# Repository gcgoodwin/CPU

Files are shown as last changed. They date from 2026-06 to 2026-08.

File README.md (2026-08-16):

# Building an 8-Bit CPU from Transistors

I have used computers for most of my life, but for a long time the processor itself was basically a black box to me. I knew that code eventually became electrical signals, but I did not understand how a group of transistors could add numbers, remember data, or follow instructions. I started this project because I wanted to work through that entire path myself instead of only reading about it.

The long-term goal is still a complete 8-bit CPU. I originally tried to plan everything at once—the ALU, registers, program counter, control unit, clock, and memory interface—but I quickly realized that physically building all of that from discrete transistors would be a huge jump. I decided to make the first hardware milestone an **8-bit adder/subtractor**, since it is both manageable and something I can later reuse inside the ALU.

## Where I am right now

I started in LTspice, where I could build a gate, simulate it, and check its output before connecting it to anything else. From there, I combined gates into half adders and full adders and tested an 8-bit ripple-carry design. Simulation gave me a working plan, but transferring that plan onto a breadboard has been a completely different challenge.

I am currently building and testing the first 1-bit stage with 2N3904 NPN transistors. The three inputs are A, B, and a SUB/Cin input, and the two outputs are SUM and carry-out. I am powering the breadboard from an Arduino's 5 V pin while I test it.

The biggest difference from LTspice is that the real circuit does not tell me where I made a mistake. I have had to learn how the breadboard rows connect, check transistor orientation, test the input switches, and trace signals with a multimeter one node at a time. Even the output LEDs caused confusion.

## Project images

### LTspice design

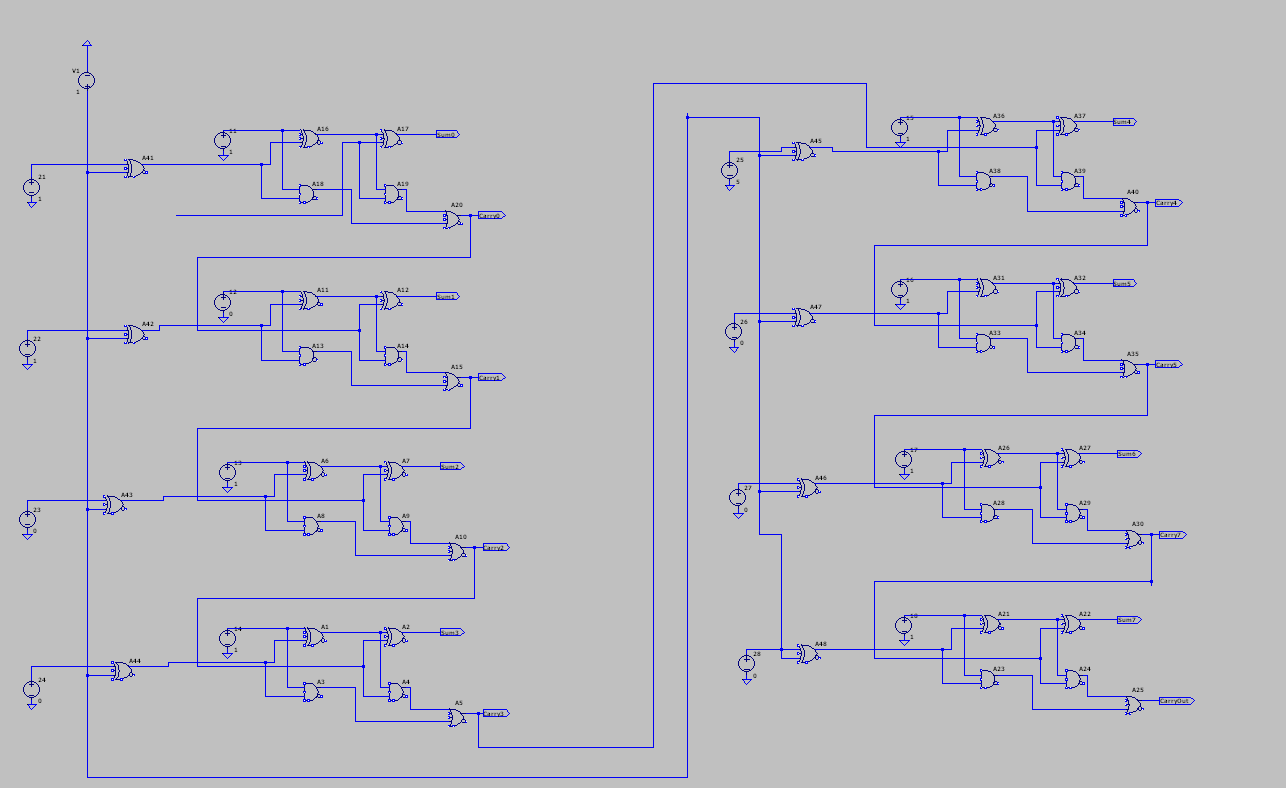
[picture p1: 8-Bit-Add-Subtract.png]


### Breadboard CAD

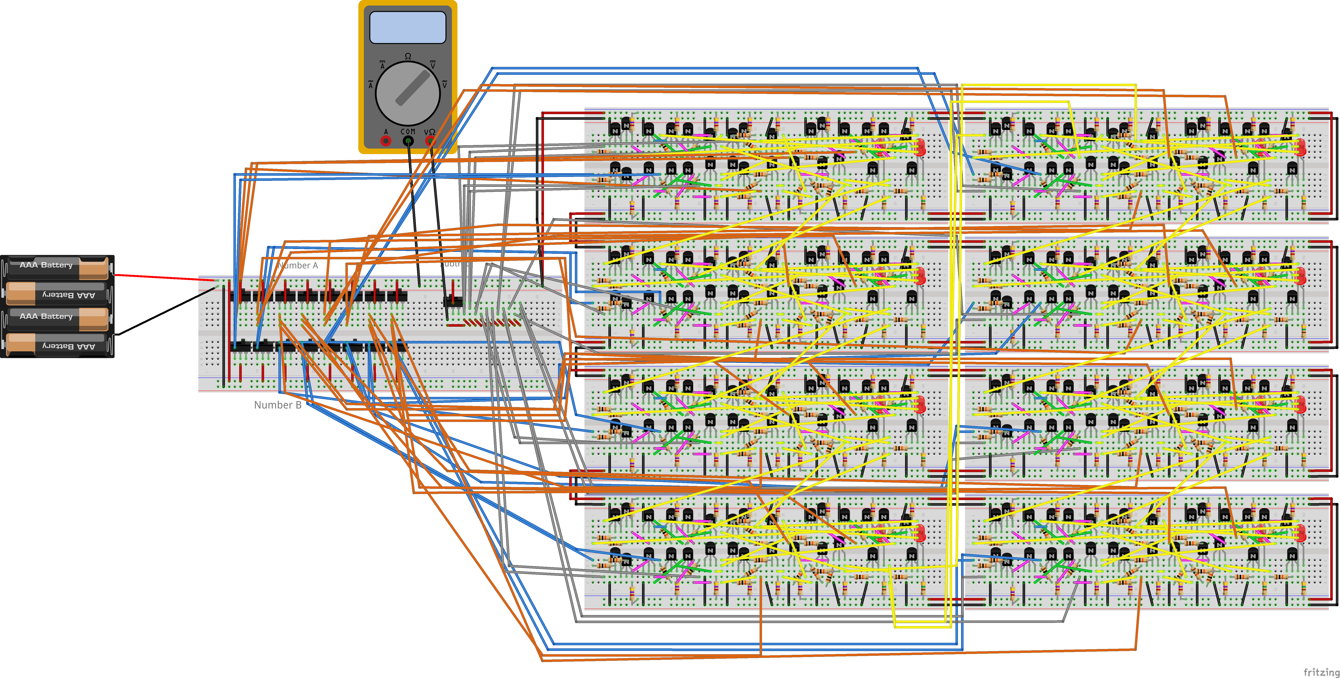
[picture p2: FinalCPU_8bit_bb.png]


### Physical build

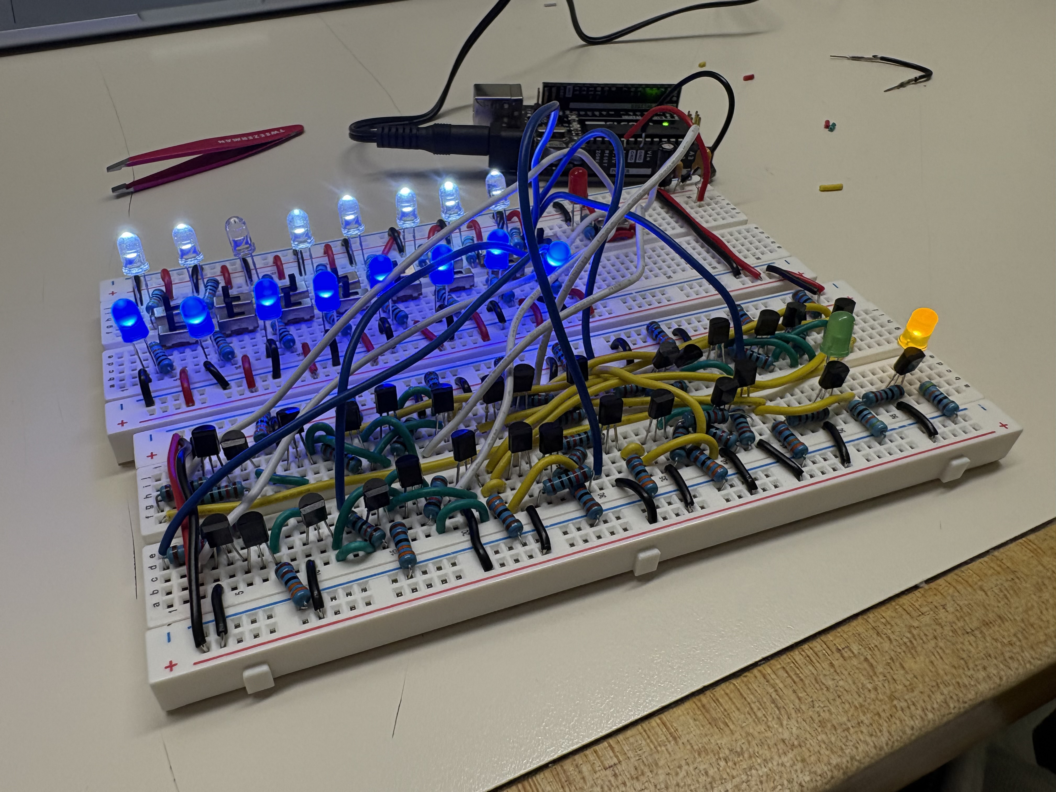
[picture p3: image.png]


## The active-low LED problem

During one test, I set `A = 1`, `B = 1`, and `Cin = 0`. I expected `SUM = 0` and `Cout = 1`, but the yellow SUM LED turned on while the green carry LED turned off. At first, I thought the full adder was producing the exact opposite of the correct answer.

After measuring the output transistor, I found that the carry collector was at 5 V while its base and emitter were at 0 V. The carry signal was actually correct. The confusing part was how I had connected the LEDs: each LED runs from 5 V through a 450 Ω resistor to an NPN collector. When the collector is LOW, the transistor sinks current and the LED turns on. When the collector is HIGH, both sides of the LED are near 5 V, so it turns off.

That means my current indicators are **active-low**:

- LED on = output `0`
- LED off = output `1`

Once I interpreted the LEDs correctly, the results followed the full-adder truth table. I added a 10 kΩ pull-up resistor to the carry collector so that its HIGH output reached 5 V instead of floating around 2.7 V. I still need to decide whether to keep the indicators active-low or spend an extra transistor and resistor on each output to make LED-on mean 1. For now, I am leaning toward keeping them active-low because the collector voltage itself is correct.

This was a useful debugging lesson because the circuit was not broken in the way I first assumed. I had to stop judging the output only by whether an LED was lit and measure the actual voltage instead.

## How addition and subtraction share one circuit

The finished 8-bit circuit will use eight full-adder stages connected in a ripple-carry arrangement. Each stage receives two data bits and the carry from the previous stage, then produces one result bit and a new carry.

For subtraction, the SUB input changes how operand B enters the adder. When `SUB = 1`, each B bit is inverted and the first carry-in is also set to 1. The adder therefore calculates:

`A + B̅ + 1 = A - B`

I originally expected subtraction to require a separate circuit, so learning that the same chain of full adders can perform both operations was one of the ideas that made me want to build this physically.

## Next steps

My immediate goal is to make the 1-bit stage reliable enough that I can duplicate it without copying an unnoticed wiring problem. After that, I will:

1. Build the remaining seven stages.
2. Connect each carry-out to the next carry-in.
3. Test addition with small values before moving to all eight bits.
4. Test subtraction and verify the two's-complement behavior.
5. Measure voltage levels between stages and check whether fan-out causes any problems.
6. Use the completed adder/subtractor as the arithmetic starting point for the ALU.

The later CPU stages are still plans, and I expect the design to change as I learn more from the physical build. Eventually, I want to add the remaining ALU operations, registers, a program counter, an instruction register, a control unit, a clock, and a memory interface.

## Planned ALU operations

| Opcode | Operation |
|:---:|---|
| `000` | Addition |
| `001` | Subtraction |
| `010` | Bitwise AND |
| `011` | Bitwise OR |
| `100` | Bitwise XOR |
| `101` | Bitwise NOT |
| `110` | Shift left |
| `111` | Shift right |

## Repository contents

- `ltspice/` contains my simulations for gates, adders, registers, and other CPU circuits.
- `cad/` contains the breadboard layout for the adder/subtractor.
- `docs/` contains schematics, architecture notes, screenshots, and hardware pictures.
- `journals/` records what I worked on, what failed, and what I changed.
- `parts-list/` tracks the components and cost of the physical build.

I am documenting the mistakes along with the finished circuits because being able to explain why something failed is part of understanding how it works. By the end of the project, I do not just want a processor that produces the right outputs. I want to know what every major section is doing and why it is connected the way it is.

## Author

**Goodwin Chen**  
Summer 2026

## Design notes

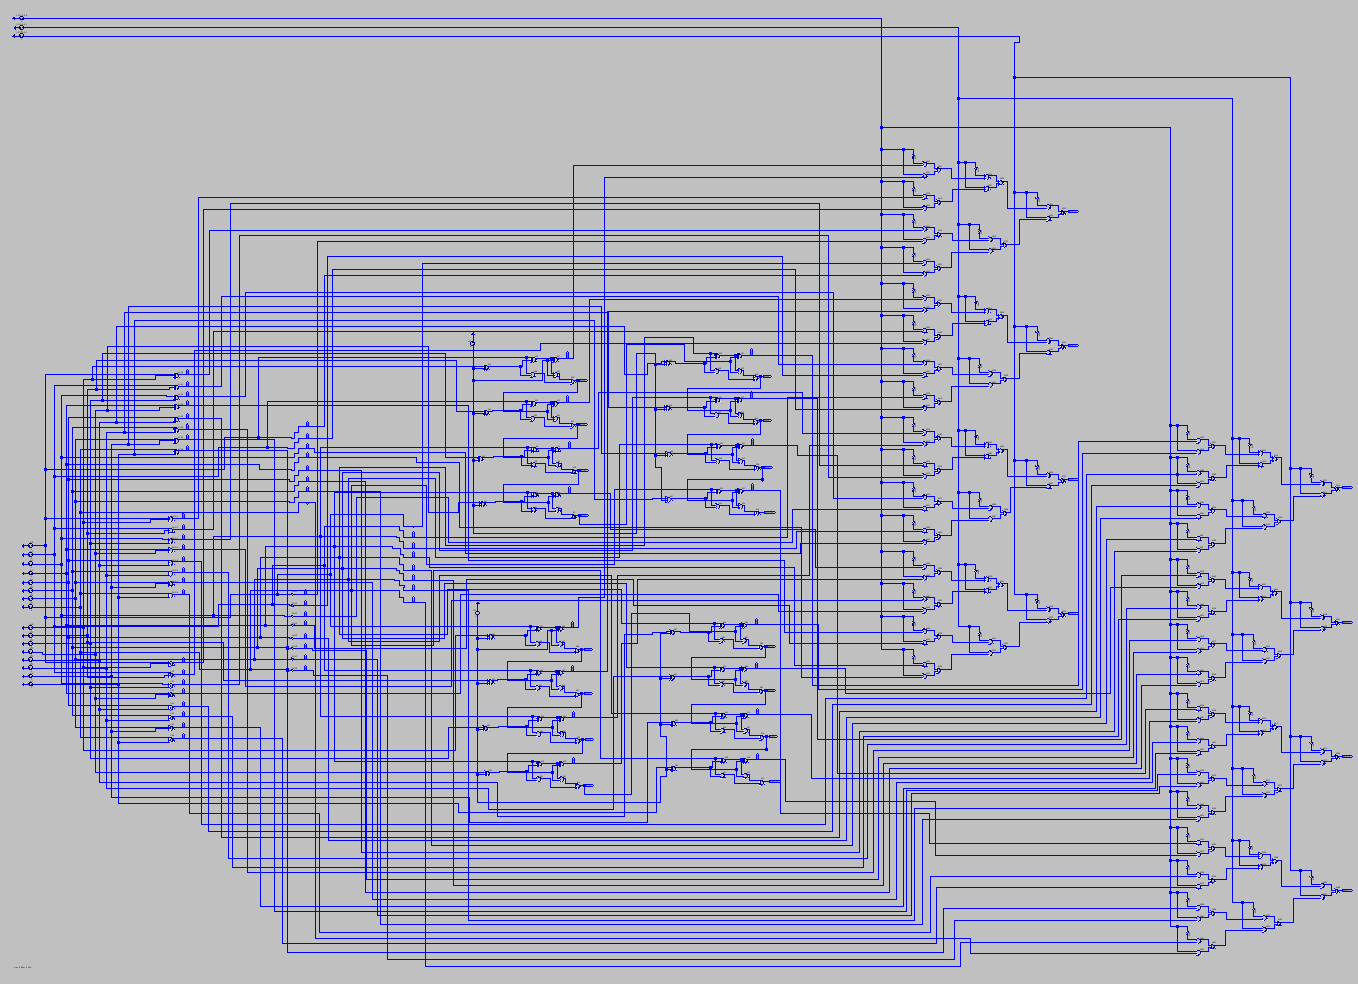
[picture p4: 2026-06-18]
Schematics/FULL-ALU-Schematic.png

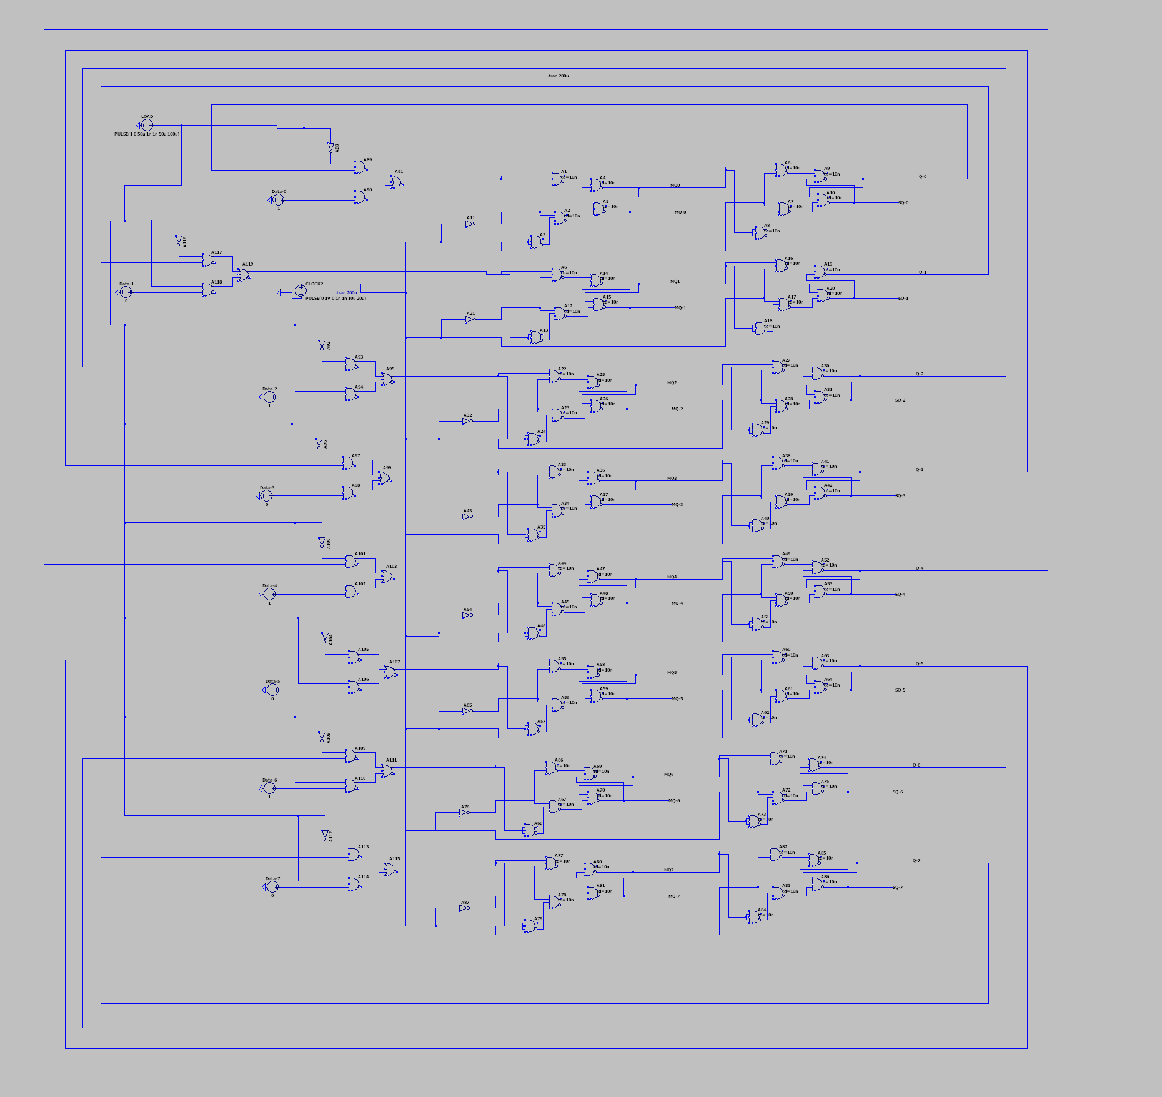
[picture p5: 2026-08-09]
Schematics/Screenshot 2026-08-08 at 11.20.06 PM.png

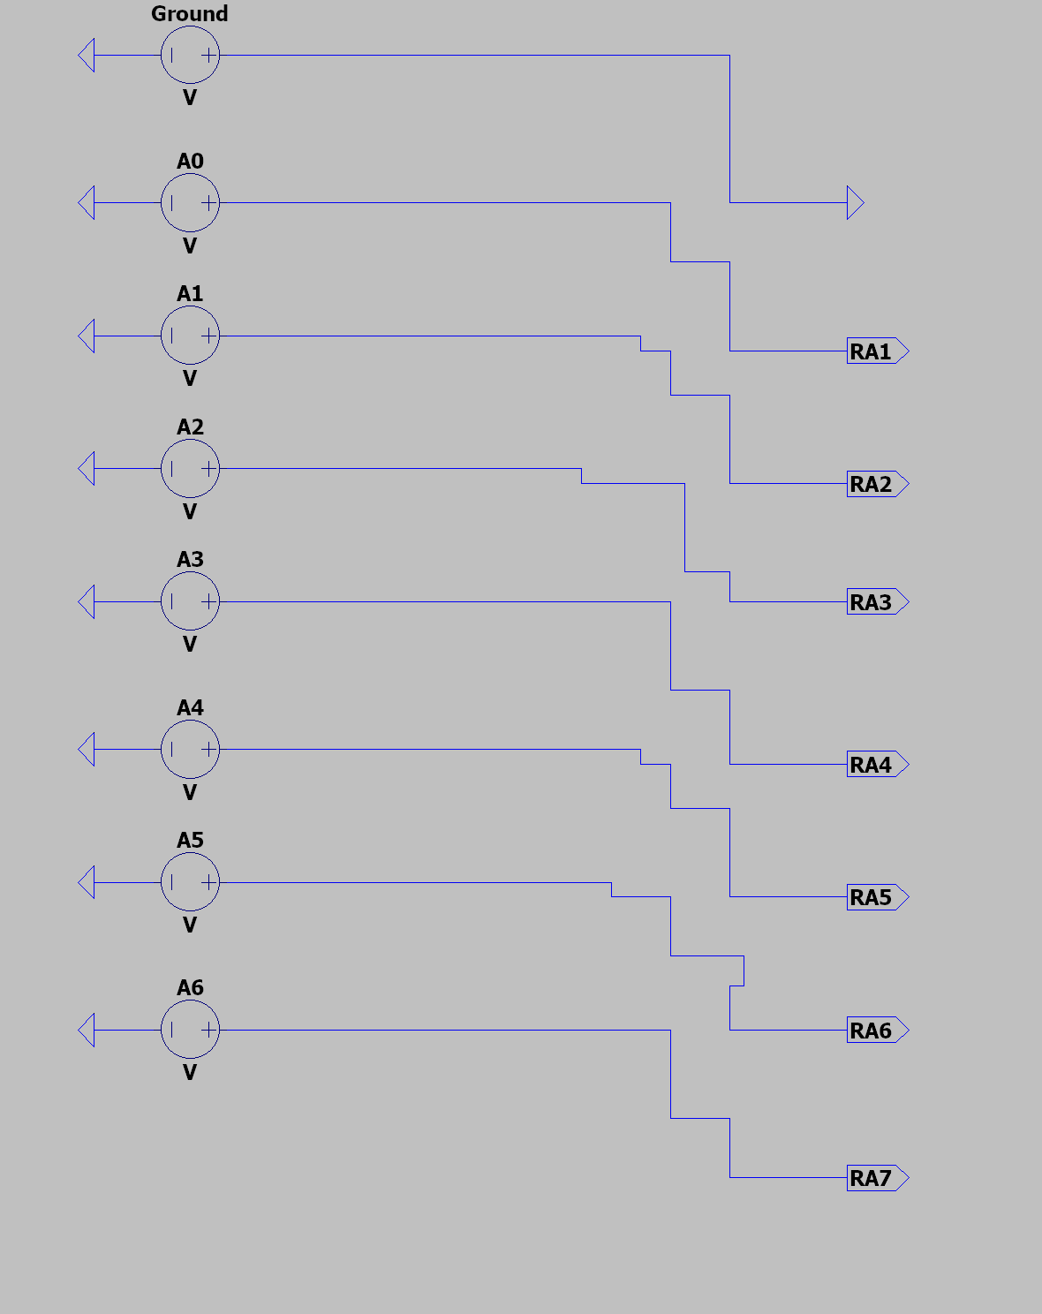
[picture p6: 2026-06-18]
Schematics/8-Bit-ShiftLeft.png

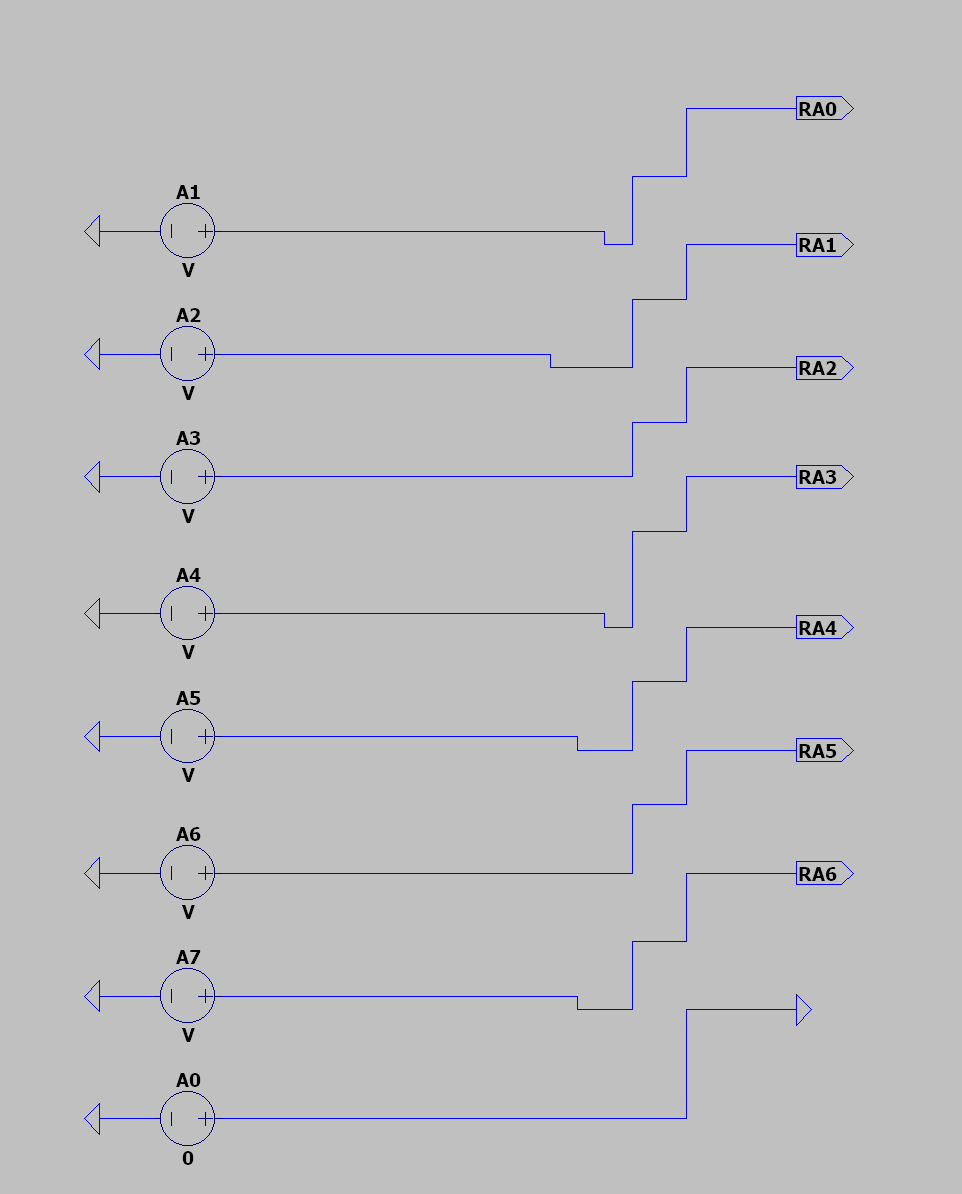
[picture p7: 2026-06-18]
Schematics/8-Bit-ShiftRight.png

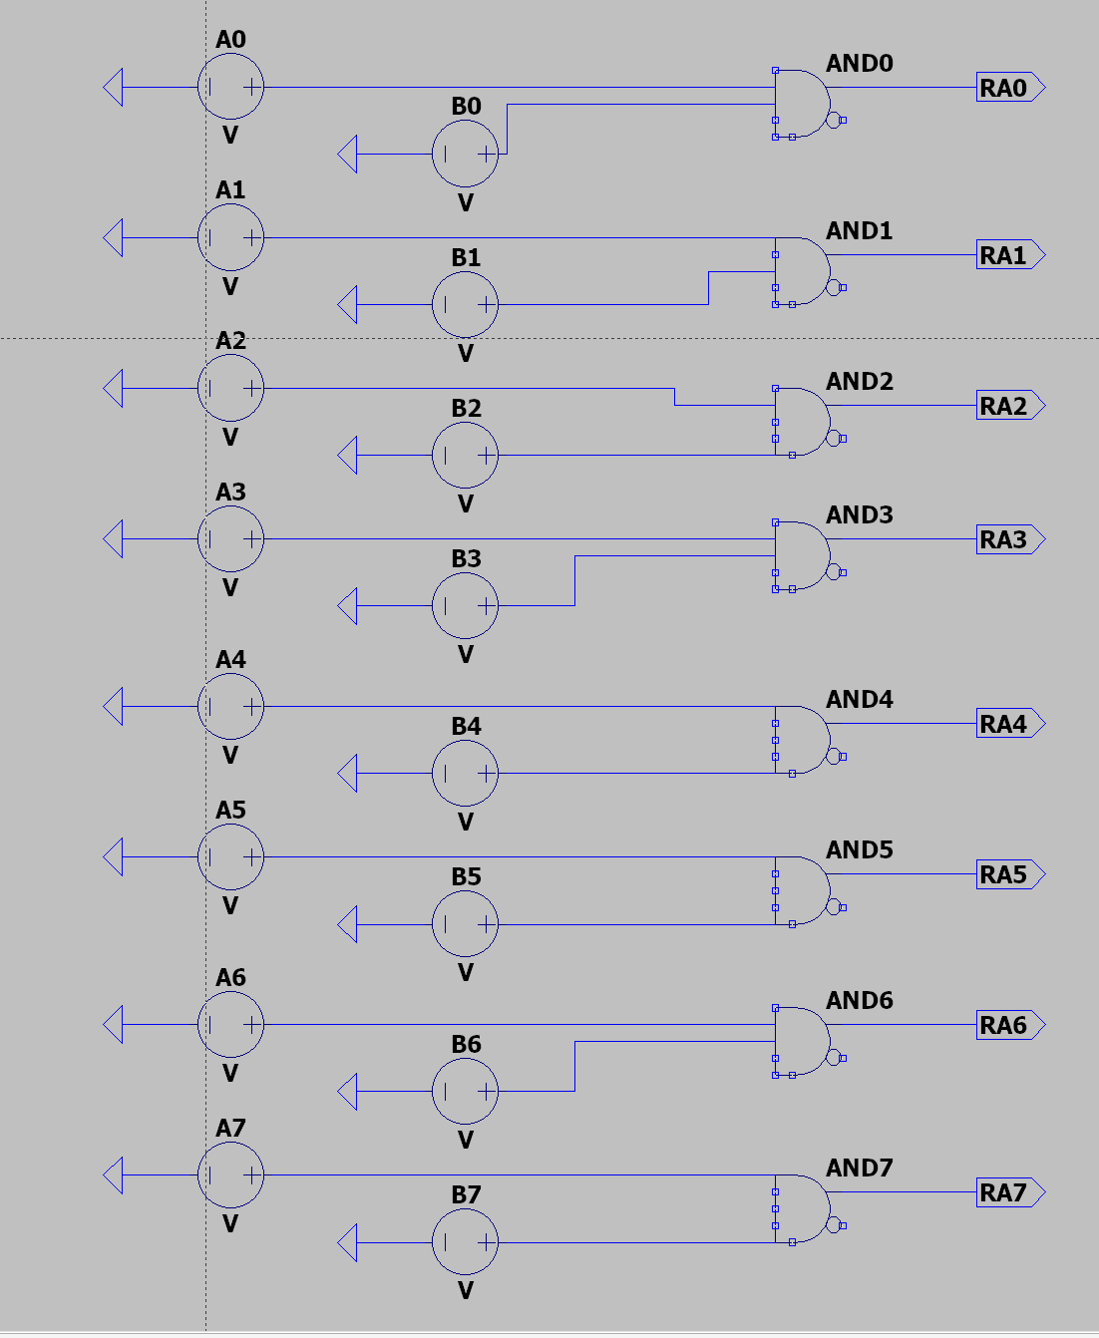
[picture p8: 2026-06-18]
Schematics/8-Bit-AND.png

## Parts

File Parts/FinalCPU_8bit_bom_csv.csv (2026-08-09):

Label | Part Type | mn | mpn | part number
LED1 | Red (633nm) LED
LED2 | Red (633nm) LED
LED3 | Red (633nm) LED
LED4 | Red (633nm) LED
LED5 | Red (633nm) LED
LED6 | Red (633nm) LED
LED7 | Red (633nm) LED
LED8 | Red (633nm) LED
LED9 | Red (633nm) LED
LED10 | Red (633nm) LED
LED11 | Red (633nm) LED
LED12 | Red (633nm) LED
LED13 | Red (633nm) LED
LED14 | Red (633nm) LED
LED15 | Red (633nm) LED
LED16 | Red (633nm) LED
Q2 | NPN-Transistor
Q3 | NPN-Transistor
Q4 | NPN-Transistor
Q5 | NPN-Transistor
Q6 | NPN-Transistor
Q7 | NPN-Transistor
Q8 | NPN-Transistor
Q9 | NPN-Transistor
Q10 | NPN-Transistor
Q11 | NPN-Transistor
Q12 | NPN-Transistor
Q13 | NPN-Transistor
Q14 | NPN-Transistor
Q15 | NPN-Transistor
Q16 | NPN-Transistor
Q17 | NPN-Transistor
Q18 | NPN-Transistor
Q19 | NPN-Transistor
Q20 | NPN-Transistor
Q21 | NPN-Transistor
Q22 | NPN-Transistor
Q23 | NPN-Transistor
Q24 | NPN-Transistor
Q25 | NPN-Transistor
Q26 | NPN-Transistor
Q27 | NPN-Transistor
Q28 | NPN-Transistor
Q29 | NPN-Transistor
Q30 | NPN-Transistor
Q31 | NPN-Transistor
Q32 | NPN-Transistor
Q33 | NPN-Transistor
Q34 | NPN-Transistor
Q35 | NPN-Transistor
Q36 | NPN-Transistor
Q37 | NPN-Transistor
Q38 | NPN-Transistor
Q39 | NPN-Transistor
Q40 | NPN-Transistor
Q41 | NPN-Transistor
Q42 | NPN-Transistor
Q43 | NPN-Transistor
Q44 | NPN-Transistor
Q45 | NPN-Transistor
Q46 | NPN-Transistor
Q47 | NPN-Transistor
Q48 | NPN-Transistor
Q49 | NPN-Transistor
Q50 | NPN-Transistor
Q51 | NPN-Transistor
Q52 | NPN-Transistor
Q53 | NPN-Transistor
Q54 | NPN-Transistor
Q55 | NPN-Transistor
Q56 | NPN-Transistor
Q57 | NPN-Transistor
Q58 | NPN-Transistor
Q59 | NPN-Transistor
Q60 | NPN-Transistor
Q61 | NPN-Transistor
Q62 | NPN-Transistor
Q63 | NPN-Transistor
Q64 | NPN-Transistor
Q65 | NPN-Transistor
Q66 | NPN-Transistor
Q67 | NPN-Transistor
Q68 | NPN-Transistor
Q69 | NPN-Transistor
Q70 | NPN-Transistor
Q71 | NPN-Transistor
Q72 | NPN-Transistor
Q73 | NPN-Transistor
Q74 | NPN-Transistor
Q75 | NPN-Transistor
Q76 | NPN-Transistor
Q77 | NPN-Transistor
Q78 | NPN-Transistor
Q79 | NPN-Transistor
Q80 | NPN-Transistor
Q81 | NPN-Transistor
Q82 | NPN-Transistor
Q83 | NPN-Transistor
Q84 | NPN-Transistor
Q85 | NPN-Transistor
Q86 | NPN-Transistor
Q87 | NPN-Transistor
Q88 | NPN-Transistor
Q89 | NPN-Transistor
Q90 | NPN-Transistor
Q91 | NPN-Transistor
Q92 | NPN-Transistor
Q93 | NPN-Transistor
Q94 | NPN-Transistor
Q95 | NPN-Transistor
Q96 | NPN-Transistor
Q97 | NPN-Transistor
Q98 | NPN-Transistor
Q99 | NPN-Transistor
Q100 | NPN-Transistor
Q101 | NPN-Transistor
Q102 | NPN-Transistor
Q103 | NPN-Transistor
Q104 | NPN-Transistor
Q105 | NPN-Transistor
Q106 | NPN-Transistor
Q107 | NPN-Transistor
Q108 | NPN-Transistor
Q109 | NPN-Transistor
Q110 | NPN-Transistor
Q111 | NPN-Transistor
Q112 | NPN-Transistor
Q113 | NPN-Transistor
Q114 | NPN-Transistor
Q115 | NPN-Transistor
Q116 | NPN-Transistor
Q117 | NPN-Transistor
Q118 | NPN-Transistor
Q119 | NPN-Transistor
Q120 | NPN-Transistor
Q121 | NPN-Transistor
Q122 | NPN-Transistor
Q123 | NPN-Transistor
Q124 | NPN-Transistor
Q125 | NPN-Transistor
Q126 | NPN-Transistor
Q127 | NPN-Transistor
Q128 | NPN-Transistor
Q129 | NPN-Transistor
Q130 | NPN-Transistor
Q131 | NPN-Transistor
Q132 | NPN-Transistor
Q133 | NPN-Transistor
Q134 | NPN-Transistor
Q135 | NPN-Transistor
Q136 | NPN-Transistor
Q137 | NPN-Transistor
Q138 | NPN-Transistor
Q139 | NPN-Transistor
Q140 | NPN-Transistor
Q141 | NPN-Transistor
Q142 | NPN-Transistor
Q143 | NPN-Transistor
Q144 | NPN-Transistor
Q145 | NPN-Transistor
Q146 | NPN-Transistor
Q147 | NPN-Transistor
Q148 | NPN-Transistor
Q149 | NPN-Transistor
Q150 | NPN-Transistor
Q151 | NPN-Transistor
Q152 | NPN-Transistor
Q153 | NPN-Transistor
Q154 | NPN-Transistor
Q155 | NPN-Transistor
Q156 | NPN-Transistor
Q157 | NPN-Transistor
Q158 | NPN-Transistor
Q159 | NPN-Transistor
Q160 | NPN-Transistor
Q161 | NPN-Transistor
Q162 | NPN-Transistor
Q163 | NPN-Transistor
Q164 | NPN-Transistor
Q165 | NPN-Transistor
Q166 | NPN-Transistor
Q167 | NPN-Transistor
Q168 | NPN-Transistor
Q169 | NPN-Transistor
Q170 | NPN-Transistor
Q171 | NPN-Transistor
Q172 | NPN-Transistor
Q173 | NPN-Transistor
Q174 | NPN-Transistor
Q175 | NPN-Transistor
Q176 | NPN-Transistor
Q177 | NPN-Transistor
Q178 | NPN-Transistor
Q179 | NPN-Transistor
Q180 | NPN-Transistor
Q181 | NPN-Transistor
Q182 | NPN-Transistor
Q183 | NPN-Transistor
Q184 | NPN-Transistor
Q185 | NPN-Transistor
Q186 | NPN-Transistor
Q187 | NPN-Transistor
Q188 | NPN-Transistor
Q189 | NPN-Transistor
Q190 | NPN-Transistor
Q191 | NPN-Transistor
Q192 | NPN-Transistor
Q193 | NPN-Transistor
Q194 | NPN-Transistor
Q195 | NPN-Transistor
Q196 | NPN-Transistor
Q197 | NPN-Transistor
Q198 | NPN-Transistor
Q199 | NPN-Transistor
Q200 | NPN-Transistor
Q201 | NPN-Transistor
Q202 | NPN-Transistor
Q203 | NPN-Transistor
Q204 | NPN-Transistor
Q205 | NPN-Transistor
Q206 | NPN-Transistor
Q207 | NPN-Transistor
Q208 | NPN-Transistor
Q209 | NPN-Transistor
Q210 | NPN-Transistor
Q211 | NPN-Transistor
Q212 | NPN-Transistor
Q213 | NPN-Transistor
Q214 | NPN-Transistor
Q215 | NPN-Transistor
Q216 | NPN-Transistor
Q217 | NPN-Transistor
Q218 | NPN-Transistor
Q219 | NPN-Transistor
Q220 | NPN-Transistor
Q221 | NPN-Transistor
Q222 | NPN-Transistor
Q223 | NPN-Transistor
Q224 | NPN-Transistor
Q225 | NPN-Transistor
Q226 | NPN-Transistor
Q227 | NPN-Transistor
Q228 | NPN-Transistor
Q229 | NPN-Transistor
Q230 | NPN-Transistor
Q231 | NPN-Transistor
Q232 | NPN-Transistor
Q233 | NPN-Transistor
R5 | 10kΩ Resistor
R6 | 10kΩ Resistor
R8 | 4.7kΩ Resistor
R9 | 4.7kΩ Resistor
R10 | 4.7kΩ Resistor
R13 | 10kΩ Resistor
R14 | 10kΩ Resistor
R15 | 10kΩ Resistor
R16 | 10kΩ Resistor
R17 | 4.7kΩ Resistor
R18 | 4.7kΩ Resistor
R19 | 4.7kΩ Resistor
R20 | 10kΩ Resistor
R21 | 10kΩ Resistor
R22 | 10kΩ Resistor
R23 | 4.7kΩ Resistor
R24 | 10kΩ Resistor
R25 | 4.7kΩ Resistor
R26 | 10kΩ Resistor
R27 | 10kΩ Resistor
R28 | 10kΩ Resistor
R29 | 10kΩ Resistor
R30 | 4.7kΩ Resistor
R31 | 4.7kΩ Resistor
R32 | 10kΩ Resistor
R33 | 10kΩ Resistor
R34 | 10kΩ Resistor
R35 | 10kΩ Resistor
R36 | 4.7kΩ Resistor
R37 | 4.7kΩ Resistor
R38 | 10kΩ Resistor
R39 | 10kΩ Resistor
R40 | 4.7kΩ Resistor
R41 | 4.7kΩ Resistor
R42 | 4.7kΩ Resistor
R43 | 10kΩ Resistor
R44 | 10kΩ Resistor
R45 | 450Ω Resistor
R46 | 450Ω Resistor
R47 | 10kΩ Resistor
R48 | 10kΩ Resistor
R49 | 10kΩ Resistor
R50 | 10kΩ Resistor
R51 | 10kΩ Resistor
R52 | 10kΩ Resistor
R53 | 10kΩ Resistor
R54 | 10kΩ Resistor
R55 | 10kΩ Resistor
R56 | 10kΩ Resistor
R57 | 10kΩ Resistor
R58 | 10kΩ Resistor
R59 | 450Ω Resistor
R60 | 450Ω Resistor
R61 | 4.7kΩ Resistor
R62 | 4.7kΩ Resistor
R63 | 4.7kΩ Resistor
R64 | 4.7kΩ Resistor
R65 | 4.7kΩ Resistor
R66 | 4.7kΩ Resistor
R67 | 4.7kΩ Resistor
R68 | 4.7kΩ Resistor
R69 | 4.7kΩ Resistor
R70 | 4.7kΩ Resistor
R71 | 4.7kΩ Resistor
R72 | 4.7kΩ Resistor
R73 | 4.7kΩ Resistor
R74 | 4.7kΩ Resistor
R75 | 4.7kΩ Resistor
R76 | 10kΩ Resistor
R77 | 10kΩ Resistor
R78 | 10kΩ Resistor
R79 | 10kΩ Resistor
R80 | 10kΩ Resistor
R81 | 10kΩ Resistor
R82 | 10kΩ Resistor
R83 | 10kΩ Resistor
R84 | 10kΩ Resistor
R85 | 10kΩ Resistor
R86 | 10kΩ Resistor
R87 | 10kΩ Resistor
R88 | 10kΩ Resistor
R89 | 10kΩ Resistor
R90 | 10kΩ Resistor
R91 | 10kΩ Resistor
R92 | 10kΩ Resistor
R93 | 10kΩ Resistor
R94 | 10kΩ Resistor
R95 | 10kΩ Resistor
R96 | 10kΩ Resistor
R97 | 10kΩ Resistor
R98 | 10kΩ Resistor
R99 | 10kΩ Resistor
R100 | 450Ω Resistor
R101 | 450Ω Resistor
R102 | 4.7kΩ Resistor
R103 | 4.7kΩ Resistor
R104 | 4.7kΩ Resistor
R105 | 4.7kΩ Resistor
R106 | 4.7kΩ Resistor
R107 | 4.7kΩ Resistor
R108 | 4.7kΩ Resistor
R109 | 4.7kΩ Resistor
R110 | 4.7kΩ Resistor
R111 | 4.7kΩ Resistor
R112 | 4.7kΩ Resistor
R113 | 4.7kΩ Resistor
R114 | 4.7kΩ Resistor
R115 | 4.7kΩ Resistor
R116 | 4.7kΩ Resistor
R117 | 10kΩ Resistor
R118 | 10kΩ Resistor
R119 | 10kΩ Resistor
R120 | 10kΩ Resistor
R121 | 10kΩ Resistor
R122 | 10kΩ Resistor
R123 | 10kΩ Resistor
R124 | 10kΩ Resistor
R125 | 10kΩ Resistor
R126 | 10kΩ Resistor
R127 | 10kΩ Resistor
R128 | 10kΩ Resistor
R129 | 10kΩ Resistor
R130 | 10kΩ Resistor
R131 | 10kΩ Resistor
R132 | 10kΩ Resistor
R133 | 10kΩ Resistor
R134 | 10kΩ Resistor
R135 | 10kΩ Resistor
R136 | 10kΩ Resistor
R137 | 10kΩ Resistor
R138 | 10kΩ Resistor
R139 | 10kΩ Resistor
R140 | 10kΩ Resistor
R141 | 450Ω Resistor
R142 | 450Ω Resistor
R143 | 4.7kΩ Resistor
R144 | 4.7kΩ Resistor
R145 | 4.7kΩ Resistor
R146 | 4.7kΩ Resistor
R147 | 4.7kΩ Resistor
R148 | 4.7kΩ Resistor
R149 | 4.7kΩ Resistor
R150 | 4.7kΩ Resistor
R151 | 4.7kΩ Resistor
R152 | 4.7kΩ Resistor
R153 | 4.7kΩ Resistor
R154 | 4.7kΩ Resistor
R155 | 4.7kΩ Resistor
R156 | 4.7kΩ Resistor
R157 | 4.7kΩ Resistor
R158 | 10kΩ Resistor
R159 | 10kΩ Resistor
R160 | 10kΩ Resistor
R161 | 10kΩ Resistor
R162 | 10kΩ Resistor
R163 | 10kΩ Resistor
R164 | 10kΩ Resistor
R165 | 10kΩ Resistor
R166 | 10kΩ Resistor
R167 | 10kΩ Resistor
R168 | 10kΩ Resistor
R169 | 10kΩ Resistor
R170 | 10kΩ Resistor
R171 | 10kΩ Resistor
R172 | 10kΩ Resistor
R173 | 10kΩ Resistor
R174 | 10kΩ Resistor
R175 | 10kΩ Resistor
R176 | 10kΩ Resistor
R177 | 10kΩ Resistor
R178 | 10kΩ Resistor
R179 | 10kΩ Resistor
R180 | 10kΩ Resistor
R181 | 10kΩ Resistor
R182 | 450Ω Resistor
R183 | 450Ω Resistor
R184 | 4.7kΩ Resistor
R185 | 4.7kΩ Resistor
R186 | 4.7kΩ Resistor
R187 | 4.7kΩ Resistor
R188 | 4.7kΩ Resistor
R189 | 4.7kΩ Resistor
R190 | 4.7kΩ Resistor
R191 | 4.7kΩ Resistor
R192 | 4.7kΩ Resistor
R193 | 4.7kΩ Resistor
R194 | 4.7kΩ Resistor
R195 | 4.7kΩ Resistor
R196 | 4.7kΩ Resistor
R197 | 4.7kΩ Resistor
R198 | 4.7kΩ Resistor
R199 | 10kΩ Resistor
R200 | 10kΩ Resistor
R201 | 10kΩ Resistor
R202 | 10kΩ Resistor
R203 | 10kΩ Resistor
R204 | 10kΩ Resistor
R205 | 10kΩ Resistor
R206 | 10kΩ Resistor
R207 | 10kΩ Resistor
R208 | 10kΩ Resistor
R209 | 10kΩ Resistor
R210 | 10kΩ Resistor
R211 | 10kΩ Resistor
R212 | 10kΩ Resistor
R213 | 10kΩ Resistor
R214 | 10kΩ Resistor
R215 | 10kΩ Resistor
R216 | 10kΩ Resistor
R217 | 10kΩ Resistor
R218 | 10kΩ Resistor
R219 | 10kΩ Resistor
R220 | 10kΩ Resistor
R221 | 10kΩ Resistor
R222 | 10kΩ Resistor
R223 | 450Ω Resistor
R224 | 450Ω Resistor
R225 | 4.7kΩ Resistor
R226 | 4.7kΩ Resistor
R227 | 4.7kΩ Resistor
R228 | 4.7kΩ Resistor
R229 | 4.7kΩ Resistor
R230 | 4.7kΩ Resistor
R231 | 4.7kΩ Resistor
R232 | 4.7kΩ Resistor
R233 | 4.7kΩ Resistor
R234 | 4.7kΩ Resistor
R235 | 4.7kΩ Resistor
R236 | 4.7kΩ Resistor
R237 | 4.7kΩ Resistor
R238 | 4.7kΩ Resistor
R239 | 4.7kΩ Resistor
R240 | 10kΩ Resistor
R241 | 10kΩ Resistor
R242 | 10kΩ Resistor
R243 | 10kΩ Resistor
R244 | 10kΩ Resistor
R245 | 10kΩ Resistor
R246 | 10kΩ Resistor
R247 | 10kΩ Resistor
R248 | 10kΩ Resistor
R249 | 10kΩ Resistor
R250 | 10kΩ Resistor
R251 | 10kΩ Resistor
R252 | 10kΩ Resistor
R253 | 10kΩ Resistor
R254 | 10kΩ Resistor
R255 | 10kΩ Resistor
R256 | 10kΩ Resistor
R257 | 10kΩ Resistor
R258 | 10kΩ Resistor
R259 | 10kΩ Resistor
R260 | 10kΩ Resistor
R261 | 10kΩ Resistor
R262 | 10kΩ Resistor
R263 | 10kΩ Resistor
R264 | 450Ω Resistor
R265 | 450Ω Resistor
R266 | 4.7kΩ Resistor
R267 | 4.7kΩ Resistor
R268 | 4.7kΩ Resistor
R269 | 4.7kΩ Resistor
R270 | 4.7kΩ Resistor
R271 | 4.7kΩ Resistor
R272 | 4.7kΩ Resistor
R273 | 4.7kΩ Resistor
R274 | 4.7kΩ Resistor
R275 | 4.7kΩ Resistor
R276 | 4.7kΩ Resistor
R277 | 4.7kΩ Resistor
R278 | 4.7kΩ Resistor
R279 | 4.7kΩ Resistor
R280 | 4.7kΩ Resistor
R281 | 10kΩ Resistor
R282 | 10kΩ Resistor
R283 | 10kΩ Resistor
R284 | 10kΩ Resistor
R285 | 10kΩ Resistor
R286 | 10kΩ Resistor
R287 | 10kΩ Resistor
R288 | 10kΩ Resistor
R289 | 10kΩ Resistor
R290 | 10kΩ Resistor
R291 | 10kΩ Resistor
R292 | 10kΩ Resistor
R293 | 10kΩ Resistor
R294 | 10kΩ Resistor
R295 | 10kΩ Resistor
R296 | 10kΩ Resistor
R297 | 10kΩ Resistor
R298 | 10kΩ Resistor
R299 | 10kΩ Resistor
R300 | 10kΩ Resistor
R301 | 10kΩ Resistor
R302 | 10kΩ Resistor
R303 | 10kΩ Resistor
R304 | 10kΩ Resistor
R305 | 450Ω Resistor
R306 | 450Ω Resistor
R307 | 4.7kΩ Resistor
R308 | 4.7kΩ Resistor
R309 | 4.7kΩ Resistor
R310 | 4.7kΩ Resistor
R311 | 4.7kΩ Resistor
R312 | 4.7kΩ Resistor
R313 | 4.7kΩ Resistor
R314 | 4.7kΩ Resistor
R315 | 4.7kΩ Resistor
R316 | 4.7kΩ Resistor
R317 | 4.7kΩ Resistor
R318 | 4.7kΩ Resistor
R319 | 4.7kΩ Resistor
R320 | 4.7kΩ Resistor
R321 | 4.7kΩ Resistor
R322 | 10kΩ Resistor
R323 | 10kΩ Resistor
R324 | 10kΩ Resistor
R325 | 10kΩ Resistor
R326 | 10kΩ Resistor
R327 | 10kΩ Resistor
R328 | 10kΩ Resistor
R329 | 10kΩ Resistor
R330 | 10kΩ Resistor
R331 | 10kΩ Resistor
R332 | 10kΩ Resistor
R333 | 10kΩ Resistor
R334 | 10kΩ Resistor
R335 | 10kΩ Resistor
S1 | Toggle Switch
S2 | Toggle Switch
S3 | Toggle Switch
S4 | Toggle Switch
S5 | Toggle Switch
S6 | Toggle Switch
S7 | Toggle Switch
S8 | Toggle Switch
S9 | Toggle Switch
S10 | Toggle Switch
S11 | Toggle Switch
S12 | Toggle Switch
S13 | Toggle Switch
S14 | Toggle Switch
S15 | Toggle Switch
S16 | Toggle Switch
S17 | Toggle Switch
VCC2 | 4 x AAA Battery Mount
VM1 | Multimeter (DC Voltage)
Amount | Part Type | mn | mpn | part number
192 | 10kΩ Resistor
1 | 4 x AAA Battery Mount
120 | 4.7kΩ Resistor
16 | 450Ω Resistor
1 | Multimeter (DC Voltage)
232 | NPN-Transistor
16 | Red (633nm) LED
17 | Toggle Switch

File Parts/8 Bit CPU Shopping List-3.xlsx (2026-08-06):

Item | Quanitity | Price | Ordered | Total
830 Tie Point Breadboard (https://www.amazon.com/EL-CP-003-Breadboard-Solderless-Distribution-Connecting/dp/B01EV6LJ7G?s=industrial) | 4 | 8.99 | FALSE | 120.67
Solid-core hookup wire (https://www.amazon.com/dp/B07TX6BX47?th=1) | 1 | 15.99 | FALSE
NPN Transisters 200x (https://www.amazon.com/BOJACK-2N3904-General-Purpose-Transistors/dp/B07T4ZJ76B) | 2 | 6.99 | FALSE
Resisters (https://www.amazon.com/BOJACK-Values-Resistor-Resistors-Assortment/dp/B08FD1XVL6?th=1) | 1 | 9.99 | FALSE
LED 3mm OR 5mm (https://www.amazon.com/CHANZON-Assortment-Colors-Clear-Transparent/dp/B01AUI4VSI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) | 1 | 6.99 | FALSE
3-Pin Switches (https://www.amazon.com/EGSCST-Switches-Position-Miniature-Vertical/dp/B0FNK8B1YV?th=1) | 1 | 8.99 | FALSE
Power Supply (https://www.amazon.com/Blomiky-2200mAH-Rechargeable-Battery-Charger/dp/B07FXVHT32) | 1 | 13.79 | FALSE
SM 2 Adapter for Battery (https://www.amazon.com/yueton-Pairs-Pins-Female-Connector/dp/B013L9N7KQ?s=electronics) | 1 | 5.99 | FALSE
DuPont Pins (https://www.amazon.com/gp/product/B096DNYH52/ref=ox_sc_act_title_1?smid=A1JGS66EYKMXOF&th=1) | 1 | 8.99 | FALSE
 |  |  | FALSE
 |  |  | FALSE
 |  |  | FALSE
 |  |  | FALSE
 |  |  | FALSE
 |  |  | FALSE

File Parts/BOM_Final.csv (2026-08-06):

Item | Quantity | Unit Price (USD) | Line Total (USD) | Ordered | Purchase Link
830-Tie-Point Breadboard | 4 | 8.99 | 35.96 | FALSE | https://www.amazon.com/dp/B01EV6LJ7G
Solid-Core Hookup Wire | 1 | 15.99 | 15.99 | FALSE | https://www.amazon.com/dp/B07TX6BX47
DuPont 2.54 mm Crimp Pins & 1-Pin Housings | 1 | 8.99 | 8.99 | FALSE | https://www.amazon.com/dp/B096DNYH52
NPN Transistors (200-Pack) | 2 | 6.99 | 13.98 | FALSE | https://www.amazon.com/dp/B07T4ZJ76B
Resistor Assortment | 1 | 9.99 | 9.99 | FALSE | https://www.amazon.com/dp/B08FD1XVL6
LED Pack (3 mm or 5 mm) | 1 | 6.99 | 6.99 | FALSE | https://www.amazon.com/dp/B01AUI4VSI
3-Pin SPDT Switches | 1 | 8.99 | 8.99 | FALSE | https://www.amazon.com/dp/B0FNK8B1YV
4.8 V Power Supply | 1 | 13.99 | 13.79 | FALSE | https://www.amazon.com/dp/B07FXVHT32
SM-2 Battery Adapter | 1 | 5.99 | 5.99 | FALSE | https://www.amazon.com/dp/B013L9N7KQ
TOTAL |  |  | 120.67

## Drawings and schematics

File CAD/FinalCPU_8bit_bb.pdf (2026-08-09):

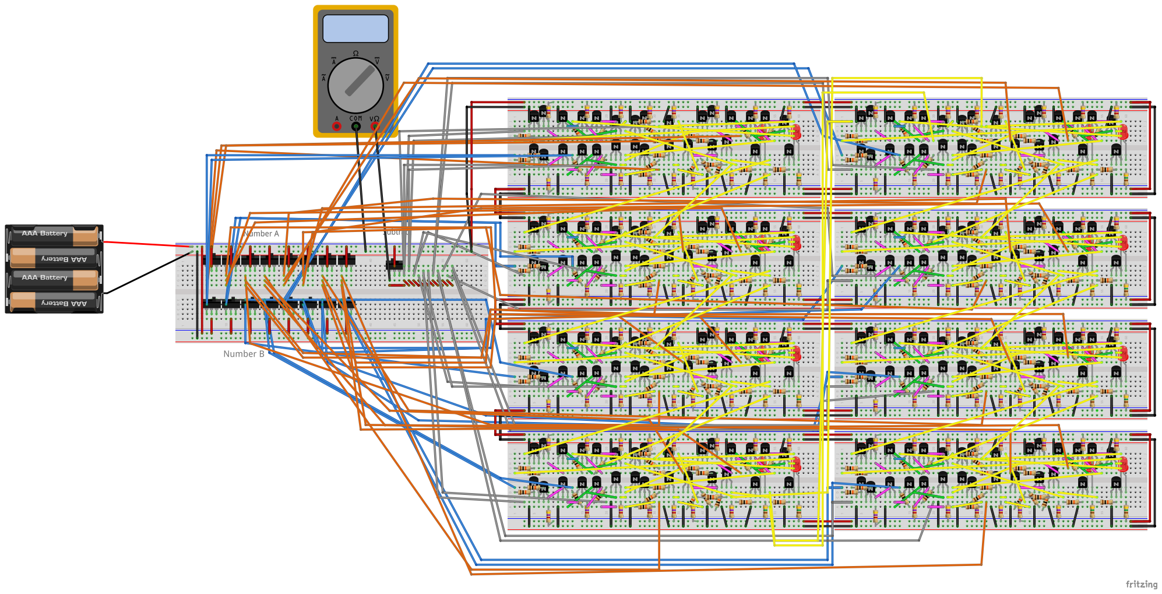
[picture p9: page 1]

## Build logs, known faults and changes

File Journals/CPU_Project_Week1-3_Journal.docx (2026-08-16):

CPU PROJECT

Three-Week Development Journal

Transistor-Level Logic, LTspice Simulation, PyRTL Conversion,
and Physical Adder Design

Student | Goodwin Chen
Project period | Three weeks, Summer 2026
Estimated work completed | Approximately 42 hours

A record of completed design, simulation, debugging, and documentation work

Project Description

I am building an 8-bit CPU from the transistor and gate level upward. The current physical hardware milestone is an 8-bit ripple-carry adder constructed from discrete NPN transistors. To reach that point, I designed and tested the required logic gates, full adders, multiplexers, shifting circuits, and an eight-function ALU in LTspice. I also developed a PyRTL-to-LTspice converter that translates digital designs into LTspice netlists and expanded it to support arithmetic, multiplexers, registers, clocked circuits, and feedback. For the physical implementation, I created a detailed one-bit full-adder layout in Fritzing, planned the complete eight-stage adder assembly, and prepared a professional bill of materials and budget. The adder serves as the arithmetic foundation for the larger CPU documented in the GitHub repository.

Journal scope: This journal records work already completed. Because I did not track every session with a timer, the hour totals are professional estimates based on the amount of design, simulation, debugging, and documentation completed.

Progress at a Glance

Week | Primary Focus | Major Deliverables | Hours
1 | LTspice logic and ALU design | Transistor-level gates, full adder, ripple-carry structure, shifts, multiplexers, and complete 8-bit ALU | 16
2 | PyRTL-to-LTspice converter | Operation mapping, reusable cells, register support, DFF validation, 8-bit register, and 4-bit counter | 15
3 | Physical layout and build planning | Fritzing full-adder layout, 8-bit assembly plan, truth-table verification, BOM, and budget | 11
Total | | Estimated completed work | 42

WEEK 1 | Transistor-Level Logic and Full ALU Assembly | 16 HOURS

OBJECTIVE

Design and simulate the transistor-level combinational logic required for an 8-bit arithmetic logic unit, then combine the individual functions through multiplexers into one complete ALU schematic.

Work Completed

- Created LTspice schematics for the inverter, AND, OR, XOR, and other fundamental logic functions needed by the datapath.
- Built and tested a one-bit full adder with A, B, and carry-in inputs and separate SUM and carry-out outputs.
- Expanded the one-bit design into a multi-bit ripple-carry structure by routing each stage’s carry output into the next stage’s carry input.
- Implemented subtraction through two’s-complement logic, including inversion of the B input and the required carry-in behavior.
- Designed separate shift-left and shift-right paths, including the grounded bit introduced at the empty end of each shift.
- Built multiplexer trees to select among arithmetic, logic, and shift operations.
- Assembled the complete eight-function, 8-bit ALU schematic and organized the buses for A, B, operation-select inputs, results, and carry signals.
- Debugged wiring faults involving the least significant bit, ground connections, shared branches, and overdefined parallel voltage sources.
- Verified representative operations in LTspice, including 5 + 3, 5 - 3, XOR, and shifting.

Design Documentation Produced

- Individual transistor-level gate diagrams
- One-bit full-adder schematic
- Eight-bit ripple-carry adder structure
- Shift-left and shift-right diagrams
- Multiplexer selection network
- Complete 8-bit ALU assembly
- LTspice waveform captures showing correct outputs

Technical Reflection

This stage established the logic foundation of the CPU. The most important lesson was that correct Boolean equations are not enough by themselves; bus ordering, carry direction, grounding, and node connectivity must also be exact. Debugging the ALU required following individual bits through the circuit and checking whether each wire represented the intended signal.

WEEK 2 | PyRTL-to-LTspice Converter and Sequential Logic | 15 HOURS

OBJECTIVE

Automate the translation of PyRTL hardware descriptions into LTspice circuits and expand the converter beyond isolated combinational gates to support reusable arithmetic cells, multiplexers, registers, clocks, and feedback.

Work Completed

- Developed a Python converter that reads a PyRTL working block and writes an LTspice .cir netlist.
- Started with support for AND, OR, XOR, NAND, NOT, and direct wire operations using an embedded transistor-level gate library.
- Added optional PyRTL synthesis so complex combinational expressions could be lowered into simpler logic operations.
- Expanded direct operation mapping for multiplexers, constants, bus wiring, concatenation, bit selection, arithmetic, and comparisons.
- Created reusable LTspice standard cells for INV, NAND2, AND2, NOR2, OR2, XOR2, XNOR2, MUX2, FULLADDER, and DFF.
- Added register handling so a multi-bit PyRTL register is automatically expanded into one D flip-flop per bit with a shared clock.
- Generated and tested example circuits including a full adder, synthesized 2-bit adder, 8-bit register, register with load behavior, and 4-bit synchronous counter.
- Diagnosed a race-through problem in the original transistor-level DFF when the output fed directly back through an adder into its input.
- Replaced the large-circuit register cell with LTspice’s native edge-triggered DFLOP while keeping the combinational gates transistor-level.
- Verified the corrected counter waveform as it advanced through the expected binary sequence.

Converter Capabilities Demonstrated

Category | Supported Behavior
Basic logic | AND, OR, XOR, NAND, NOT
Wiring and buses | Direct wires, constants, bit selection, and concatenation
Combinational modules | Multiplexers, adders, subtractors, multipliers, and comparators
Sequential modules | Registers, shared clock generation, initialization, and feedback
Validation circuits | 8-bit register and 4-bit synchronous counter

Technical Reflection

The counter became an important regression test because it combined arithmetic, clocked state, and immediate feedback. A DFF that appeared correct in isolation still failed when its output changed the next input during the same clock transition. Fixing the reusable DFF cell corrected the underlying sequential behavior without adding counter-specific logic, preserving the converter’s generalized architecture.

WEEK 3 | Fritzing Layout, Physical Full-Adder Design, and Build Planning | 11 HOURS

OBJECTIVE

Translate the simulated logic into a physical breadboard plan using discrete NPN transistors, verify the one-bit full-adder structure, and prepare the complete parts and assembly plan for an 8-bit ripple-carry adder.

Tutorial Work

To prepare for the physical build, I used tutorial material as a reference and worked through the collector, base, and emitter roles of the 2N3904, then traced how an NPN stage behaves as a switch and inverter in resistor-transistor logic. I then applied those ideas in Fritzing by planning transistor and resistor placement, power rails, switches, and LED indicators; from there I developed the one-bit full-adder layout, checked all eight A/B/carry-in input combinations against the truth table, and expanded the same structure into the eight-stage ripple-carry plan.

Work Completed

- Used tutorial material as a reference while studying the collector, base, and emitter roles of the 2N3904 NPN transistor and how NPN stages behave as switches and inverters in resistor-transistor logic.
- Used Fritzing to plan transistor placement, breadboard routing, power rails, resistor placement, switches, and LED indicators.
- Developed and refined a complete one-bit full-adder layout with clearly identified A, B, carry-in, SUM, and carry-out signals.
- Checked the full-adder behavior against all eight input combinations in the truth table.
- Planned the full eight-stage ripple-carry assembly by repeating the one-bit module and connecting each carry-out to the next stage’s carry-in.
- Selected breadboards, 22 AWG solid-core wire, 2N3904 transistors, resistor values, LEDs, three-pin SPDT switches, and a 4.8 V rechargeable power source.
- Prepared a GitHub-ready bill of materials with product links, quantities, purposes, and estimated prices.
- Calculated an estimated component total of $83.93 before tax and shipping and recommended a working budget of approximately $90.

Full-Adder Verification Table

A | B | Cin | SUM | Cout
0 | 0 | 0 | 0 | 0
0 | 0 | 1 | 1 | 0
0 | 1 | 0 | 1 | 0
0 | 1 | 1 | 0 | 1
1 | 0 | 0 | 1 | 0
1 | 0 | 1 | 0 | 1
1 | 1 | 0 | 0 | 1
1 | 1 | 1 | 1 | 1

Eight-Bit Assembly Structure

FA0: A0 + B0 + Cin -> S0 + C1

FA1: A1 + B1 + C1 -> S1 + C2

FA2: A2 + B2 + C2 -> S2 + C3

FA7: A7 + B7 + C7 -> S7 + Cout

Technical Reflection

Moving from simulation to Fritzing required a different type of precision. A circuit can be logically correct but still fail physically if transistor pins are reversed, breadboard rows are misunderstood, power rails are disconnected, or wires are difficult to trace. The Fritzing plan and parts list converted the electrical design into a buildable physical project while keeping the larger CPU goal intact.

Current Project Status

LTspice logic library: Completed and used to construct transistor-level gates, arithmetic, shifting, and selection logic.

8-bit ALU schematic: Completed and tested with representative arithmetic and logic operations.

PyRTL-to-LTspice converter: Generalized across major combinational operations and register-based sequential circuits; memory operations remain outside the current implementation.

Sequential validation: A working DFF path, 8-bit register generation, and a correct 4-bit synchronous counter waveform have been demonstrated.

Physical full-adder design: A detailed Fritzing plan and full truth-table verification are complete.

8-bit adder planning: The carry-chain structure, breadboard layout approach, component list, and budget are documented.

Project budget: Estimated component total: $83.93 before tax and shipping; recommended budget: approximately $90.

Summary of Completed Deliverables

- Transistor-level diagrams for the major logic functions
- One-bit full-adder and multi-bit ripple-carry diagrams
- Multiplexer networks and complete 8-bit ALU assembly
- LTspice waveforms for combinational and sequential tests
- Generalized PyRTL-to-LTspice conversion software
- Register, DFF, and synchronous counter test circuits
- Fritzing physical-layout plan for the full adder
- Eight-stage adder assembly plan
- Professional parts list with prices and links

Overall result: The project has progressed from individual transistor-level gates to a complete simulated ALU, a reusable conversion tool, and a physically planned full-adder module that can be repeated into an 8-bit ripple-carry adder while remaining part of the larger CPU repository.

Goodwin Chen | Summer 2026 Page

CPU PROJECT / DEVELOPMENT JOURNAL

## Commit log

2026-06-18 Create ALU-Schematic
2026-08-05 Revise README for transistor type and project structure
    Updated README to reflect use of NPN transistors instead of MOSFETs and clarified project structure.
2026-08-06 Revise BOM with updated item details
    Updated item quantities and prices in the BOM.
    [BOM_Updated.csv]
2026-08-09 Updated README and Upload of PNG & PDF on Fritzing
    [FinalCPU_8bit_bom_csv.csv]
2026-08-09 Added 8-Bit register schematic
